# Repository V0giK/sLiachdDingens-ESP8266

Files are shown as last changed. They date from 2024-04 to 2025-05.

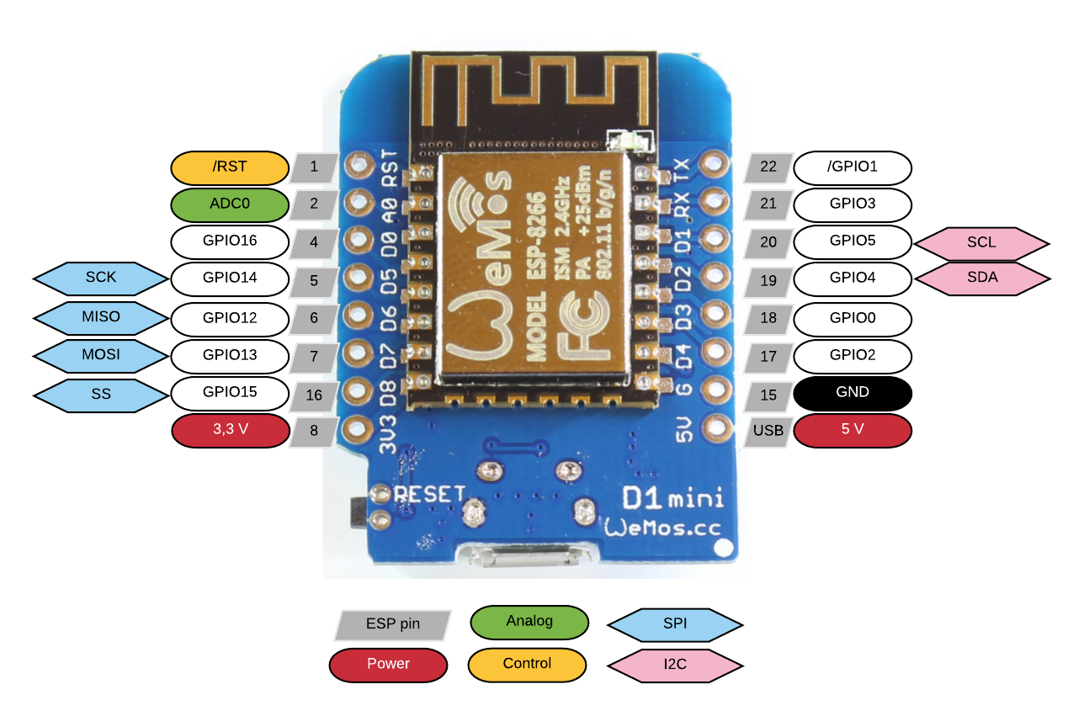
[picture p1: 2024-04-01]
KiCad/WeMos_D1_mini_Pinout.png

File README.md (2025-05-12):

# sLiachdDingens-ESP8266
Einfache 5-Kanal Modellflug Beleuchtungssteuerung

> **under developmet**

- 5 Ports (3x 500mA, 2x 1A)
- je Port 2 Steckplätze
- 1-3 S (Auto Erkennung)
- 3 LightProfile
- Betrieb auch ohne RC Anlage möglich
- Konfiguration über Browser (WLAN-AccessPoint)
	- Akku Überwachung (LowBatt Warnung, CutOff) - Spannungen einstellbar
	- RC Kanal 1 - LightProfile schalten (3 PosSchalter)
	- RC Kanal 2 - LowPower/MaxPower (2 PosSchalter oder Taster)
	- Startposition der RC Kanäle einstellbar (erst nach erreichen dieser Position kann diese geändert werden)
	- Auswählbare Blinksequencen (alle Ausgänge)
	- frei einstellbare Blinksequencen (alle Ausgänge)
	- Firmware Update möglich (OTA)
	- Download der Einstellungen möglich
	- Sicherung des Profils

---

## Aufbau

### Lötreihenfolge
1. SMD Bauteile
2. Kabel
    
### Initial Firmware Upload
> 1. Filesystem Upload - **inkl. HW.json** - (Initialwerte für EEPROM)
> 2. Firmware Upload
> 3. fertig😉

### Komponenten
- ESP8266
- ULA2003A
- ...

---

## Lizenz

Dieses Projekt steht unter der [GNU GPL v3](LICENSE).  
Copyright © 2025 V0giK

Alle Abwandlungen und Forks dieses Projekts müssen ebenfalls
unter den Bedingungen der GNU GPL v3 stehen.

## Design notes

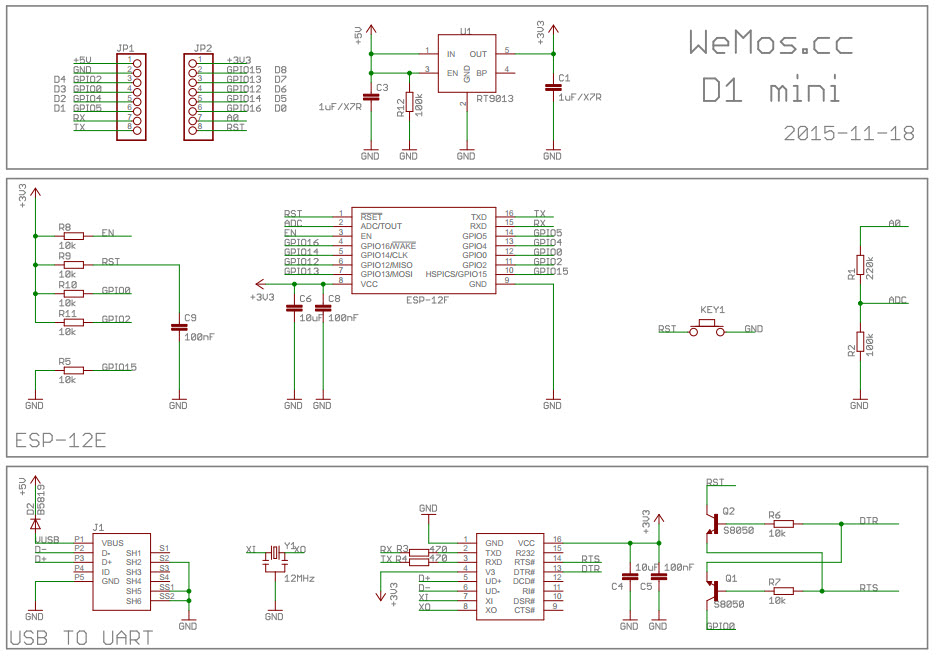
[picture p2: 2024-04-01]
KiCad/WeMos_D1_mini.png

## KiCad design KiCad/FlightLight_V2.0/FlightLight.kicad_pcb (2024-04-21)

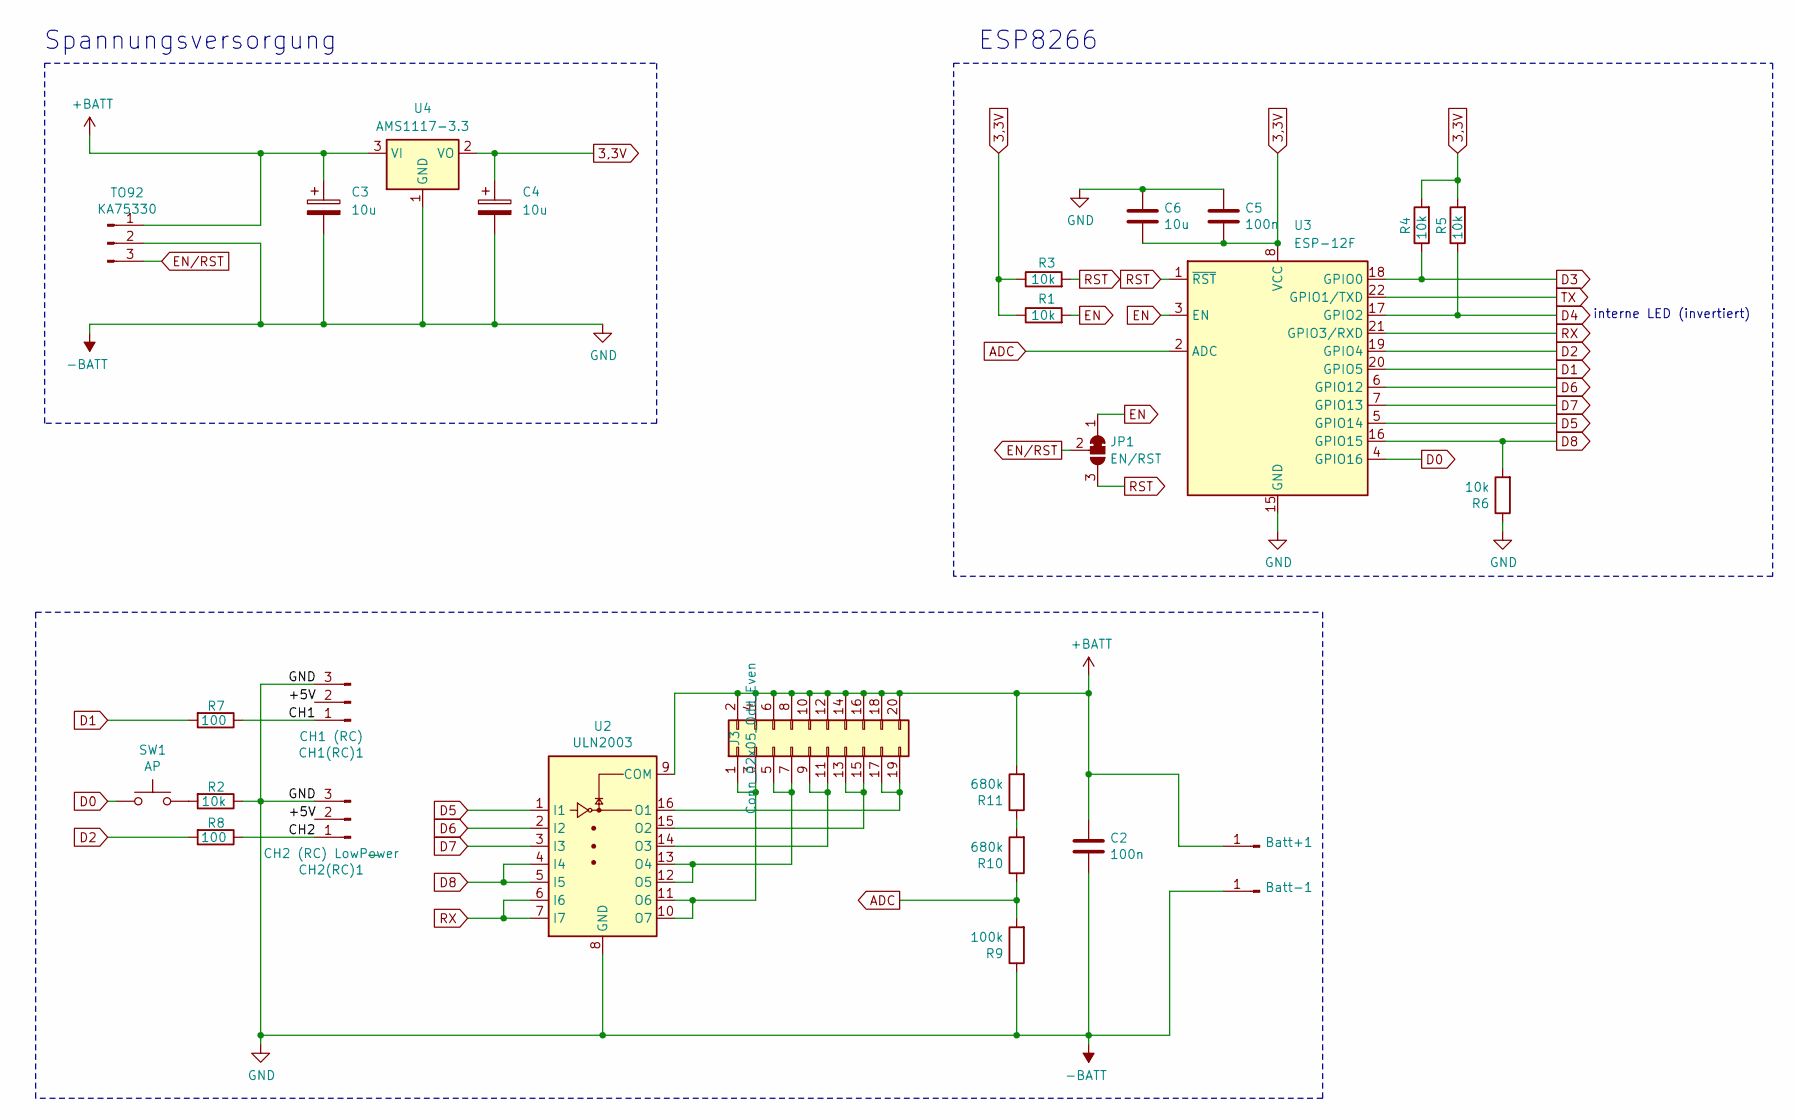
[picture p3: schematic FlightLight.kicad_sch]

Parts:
Batt+1: Batt+; Conn_01x01_2.54
Batt-1: Batt-; Conn_01x01_2.54
C2, C5: 100n; C_0805_2012Metric_Pad1.18x1.45mm_HandSolder
C3, C4, C6: 10u; C_0805_2012Metric_Pad1.18x1.45mm_HandSolder
CH1(RC)1: CH1 (RC); Conn_01x03_2.54_small
CH2(RC)1: CH2 (RC) LowPower; Conn_01x03_2.54_small
J3: Conn_02x05_Odd_Even; PinHeader_2x10_P2.54mm_Vertical
JP1: EN/RST; SolderJumper-3_P1.3mm_Bridged12_RoundedPad1.0x1.5mm
R1, R2, R3, R4, R5, R6: 10k; R_0805_2012Metric_Pad1.20x1.40mm_HandSolder
R7, R8: 100; R_0805_2012Metric_Pad1.20x1.40mm_HandSolder
R9: 100k; R_0805_2012Metric_Pad1.20x1.40mm_HandSolder
R10, R11: 680k; R_0805_2012Metric_Pad1.20x1.40mm_HandSolder
SW1: AP; SW_Push_1P1T_NO_4.5x4.5mm_H7mm
TO92: KA75330; Conn_01x03_2.54_small
U2: ULN2003; SO-16_3.9x9.9mm_P1.27mm
U3: ESP-12F; ESP-12S
U4: AMS1117-3.3; SOT-223-3_TabPin2

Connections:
3,3V: C4.1, C5.2, C6.2, R1.1, R3.1, R4.2, R5.2, U3.8 (VCC), U4.2 (VO)
+BATT: Batt+1.1, C2.1, C3.1, J3.2, J3.4, J3.6, J3.8, J3.10, J3.12, J3.14, J3.16, J3.18, J3.20, R11.2, TO92.1, U2.9 (COM), U4.3 (VI)
-BATT: Batt-1.1, C2.2, C3.2, C4.2, C5.1, C6.1, CH1(RC)1.3, CH2(RC)1.3, R2.1, R6.1, R9.1, TO92.2, U2.8 (GND), U3.15 (GND), U4.1 (GND)
/CH1: CH1(RC)1.1, R7.1
/CH2: CH2(RC)1.1, R8.1
ADC: R9.2, R10.1, U3.2 (ADC)
D0: SW1.1, U3.4 (GPIO16)
D1: R7.2, U3.20 (GPIO5)
D2: R8.2, U3.19 (GPIO4)
D3: R4.1, U3.18 (GPIO0)
D4: R5.1, U3.17 (GPIO2)
D5: U2.1 (I1), U3.5 (GPIO14)
D6: U2.2 (I2), U3.6 (GPIO12)
D7: U2.3 (I3), U3.7 (GPIO13)
D8: R6.2, U2.4 (I4), U2.5 (I5), U3.16 (GPIO15)
EN: JP1.1 (A), R1.2, U3.3 (EN)
EN/RST: JP1.2 (C), TO92.3
unnamed: J3.1, J3.3, U2.10 (O7), U2.11 (O6)
unnamed: J3.5, J3.7, U2.12 (O5), U2.13 (O4)
unnamed: J3.9, J3.11, U2.14 (O3)
unnamed: J3.13, J3.15, U2.15 (O2)
unnamed: J3.17, J3.19, U2.16 (O1)
unnamed: R2.2, SW1.2
unnamed: R10.2, R11.1
RST: JP1.3 (B), R3.2, U3.1 (~RST)
RX: U2.6 (I6), U2.7 (I7), U3.21 (GPIO3/RXD)
TX: U3.22 (GPIO1/TXD)

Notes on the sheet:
ESP8266
Spannungsversorgung
interne LED (invertiert)

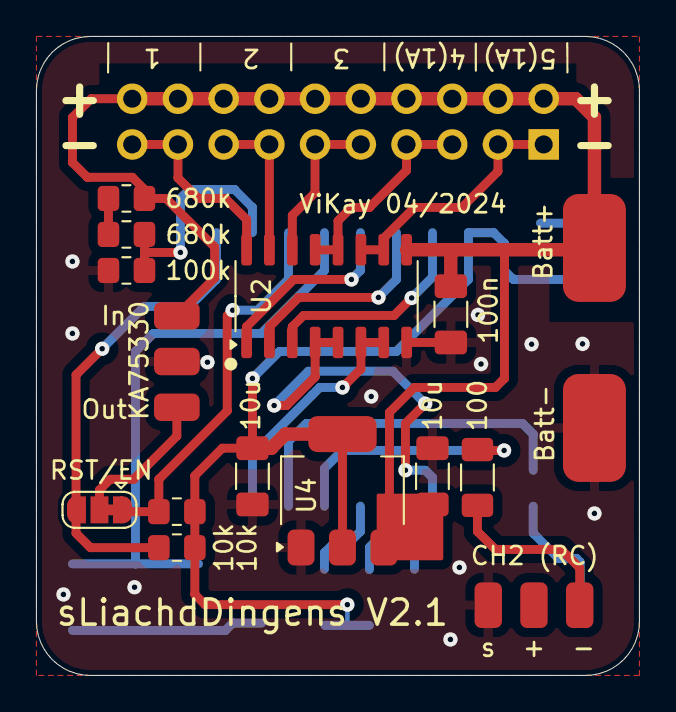
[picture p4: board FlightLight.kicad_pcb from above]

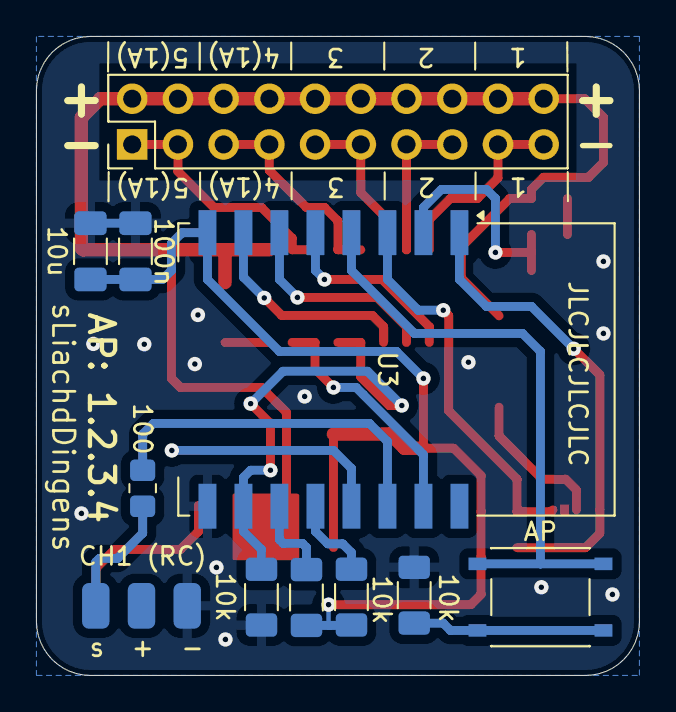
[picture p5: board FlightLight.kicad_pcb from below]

Board: 2 copper layers, 33.5 x 35.5 mm, 27 parts (11 on the bottom side), 26 nets.

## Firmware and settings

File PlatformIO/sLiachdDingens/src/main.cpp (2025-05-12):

// maim.cpp
/*
  Projekt: sLiachdDingens-ESP8266
  Copyright © 2025 V0giK

  Dieses Programm ist freie Software: Du kannst es unter den Bedingungen
  der GNU General Public License, wie von der Free Software Foundation
  veröffentlicht, weitergeben und/oder modifizieren – entweder gemäß
  Version 3 der Lizenz oder (nach Deiner Wahl) einer späteren Version.

  Der vollständige Lizenztext ist in der Datei LICENSE enthalten:
  https://github.com/V0giK/sLiachdDingens-ESP8266/blob/main/LICENSE
*/


#include <LittleFS.h>
//#include <Wire.h>

#include "main.h"
#include "Settings.h"
#include "GlobalFnc.h"
#include "RcSwitchHelper.h"


#include "globalvariables.h"
//#include "I2C_Anything.h"
#include "WiFi_WebServerHandling.h"


/* Input Pins */
#define PIN_AP D0   // AP aktivieren
#define PIN_CH_PR D1   // CH1 Profile schalten (Servoeingang)
#define PIN_CH_LP D2   // CH2 für LowPower mode
#define PIN_BATT A0 // Spannungsüberwachung Batt
/* Output Pins */
#define PIN_APACT D4  // AP aktiv (LED)
#define PIN_O1 D5
#define PIN_O2 D6
#define PIN_O3 D7
#define PIN_O4 D8
#define PIN_O5 3 // ist RX
const uint8_t outPinAr[] = {PIN_O1, PIN_O2, PIN_O3, PIN_O4, PIN_O5};

//bool bStartPrev = false;  // Loop anhalten bis alle Variablen neu bestückt sind (INI neu laden)

/* Slot Zeit */
unsigned long prevMillis = 0;   // speichert die letzte zeit des Slots
const long interval = 60;       // Interval bis nächster Slot beginnt (milliseconds)

/* RC Signal auswerten */
volatile ITR_STRUCT ITR_Ch1;
volatile ITR_STRUCT ITR_Ch2;

/* RC Schalter */
RcSwitchHelper gCH1;
RcSwitchHelper gCH2;

bool _bPrev = false; // Loop anhalten bis alle Variablen neu bestückt sind (.json neu laden)
WiFi_WebServerHandling webServer;

/***********************************************************************************************************/


void setup() {

  #ifdef DEV_SERIAL_OUT
  Serial.begin(SERIAL_SPEED);
  #endif
  if(!LittleFS.begin()) {
    #ifdef DEV_SERIAL_OUT
    Serial.println("LittleFS Mount nicht gelungen");
    #endif
  }

    /* EEPROM lesen */
  //gEeprom.loadEeprom(); // aus EEPROM
  // EEPROM beschreiben falls neue HardwareDaten vorhanden sind (HW.json)
  if(LittleFS.exists(PATH_HW)) {
    gJsonHelper.readDeleteEraseJsonHW(gEeprom);
    gEeprom.saveEeprom();

    // TODO : oder weiter machen?
    delay(200);
    ESP.restart();
  } else {
    gEeprom.loadEeprom(); // aus EEPROM
  }

  // JsonHelper initialisieren
  gJsonHelper.begin(gEeprom.getPortCount(), gEeprom.getProfileCount(), gEeprom.getSlotCount());
  
  // Config laden
  gJsonHelper.loadJsonConfig();
  // Sequence laden
  gJsonHelper.loadJsonSequence();

  // BattHelper initialisieren
  gBatt.begin(PIN_BATT, gJsonHelper.getConfigBattWarningVolt(), gJsonHelper.getConfigBattCutOffVolt(), gEeprom.getBattCalibFactor(), BATT_WARN_LOW);

  // RC Schalter initialisieren
  gCH1.begin((gJsonHelper.getSequence()->ch1Boot == 2)?1:gJsonHelper.getSequence()->ch1Boot, (gJsonHelper.getSequence()->ch1Boot == 2));
  gCH2.begin((gJsonHelper.getSequence()->ch2Boot == 2)?1:gJsonHelper.getSequence()->ch2Boot, (gJsonHelper.getSequence()->ch2Boot == 2));
  ITR_Ch1.bIsToggleSwitsch = gCH1.isToggleSwitch();
  ITR_Ch2.bIsToggleSwitsch = gCH2.isToggleSwitch();
  
  
  /* WiFi deaktivieren */
  // Wird im Constructor erledigt
  //webServer.disableWifi();

  // Serial Pin's auf GPIO tauschen  
  //pinMode(1, FUNCTION_3);  //GPIO 1 (TX) swap the pin to a GPIO.
  pinMode(3, FUNCTION_3);  //GPIO 3 (RX) swap the pin to a GPIO.

  // PinMode
  pinMode(PIN_AP, INPUT_PULLUP); // kein interner PULLUP vorhanden nur PULLDOWN
  pinMode(PIN_CH_PR, INPUT);
  pinMode(PIN_CH_LP, INPUT);
  pinMode(PIN_BATT, INPUT);
  pinMode(PIN_APACT, OUTPUT);
  pinMode(PIN_O1, OUTPUT);
  pinMode(PIN_O2, OUTPUT);
  pinMode(PIN_O3, OUTPUT);
  pinMode(PIN_O4, OUTPUT);
  pinMode(PIN_O5, OUTPUT);
  //attachInterrupt(PIN_SV, RcChange, CHANGE);
  attachInterrupt(digitalPinToInterrupt(PIN_CH_PR), RcCalcChange, CHANGE);
  attachInterrupt(digitalPinToInterrupt(PIN_CH_LP), RcLowPwrChange, CHANGE);
  
    // I2C Starten
  #ifndef DEV_SERIAL_OUT

  /*
    pinMode(1, FUNCTION_3);  //GPIO 1 (TX) swap the pin to a GPIO.
    pinMode(3, FUNCTION_3);  //GPIO 3 (RX) swap the pin to a GPIO.
    delay(200);
    Wire.begin(1, 3);
  */

    /*
     * I2C Scannen
     * - prüfen ob für Adresse ein .json vorhanden ist
     * - wenn ja Adresse in Array aufnehmen
     */
    /*
    byte i = 0;
    for(byte adr=8; adr<120; adr++){
      if(i >= EXPAND_MAX)
        break;
      Wire.beginTransmission(adr);
      if(0 == Wire.endTransmission()){
        // noch prüfen ob Exp??.json vorhanden
        if(LittleFS.exists(PATH_JSON + String("/Exp") + String(adr) + ".json")){
          gExpandAdresses[i] = adr;
          i++;
        }
      }
    }
    */
  #endif

  // Vorbelegung für den Start
  gLowPwr = gJsonHelper.getSequence()->lowPwrPercent;
  

  /*
  Wire.beginTransmission(0);
  Wire.write("W1");
  Wire.write(gPosCH1);
  Wire.write("W2");
  Wire.write(gPosCH2);
  Wire.endTransmission();
  */
  

  // Access Point aktivieren wenn Taster gedrückt
  digitalWrite(PIN_APACT, HIGH);     // AP LED off

  if(!digitalRead(PIN_AP) || DBG_AP_ON) {
    webServer.AP_starten();
    digitalWrite(PIN_APACT, LOW);  // AP LED on
  }else{
    //WiFi.mode(WIFI_SHUTDOWN);
  }

  // warten bis RC Anlage gebunden sein müsste
  delay(500);

}

void loop() {

  /* Position CH1 */
  /* Position CH2 */
  handleRcChannels();



  unsigned long curMillis = millis();
  if (curMillis - prevMillis >= interval && !getPrev()) {
    prevMillis = curMillis;

    /* VBatt */
    if(giCurSlot % 4 == 1) { // 20 Slots % 4 = 0-3; nach jeweils 4 Slots erneut prüfen (4x 0,06sec = 0,24sec)

      // Batterie Daten aktualisieren
      gBatt.refresh();
      
      // Unterspannung
      // CutOff
      if(gBatt.isCutOff()){
        setAllLightPortsOff();
        mapSlot2Port(0);
        delay(200);
        ESP.deepSleep(ESP.deepSleepMax());
      }
    }
    /* end - VBatt */

    if(giCurSlot >= gEeprom.getSlotCount()) giCurSlot = 0;
    
    // Ausgabe an die Ports
    mapSlot2Port(giCurSlot);

    #ifndef DEV_SERIAL_OUT
    /*
    Wire.beginTransmission(0);
    Wire.write("S"); Wire.write(giCurSlot);
    Wire.endTransmission();
    */
    #endif

    giCurSlot++;
    yield();
  }
  //ESP.wdtDisable(); 

}

/**
 * Slots an die Pins ausgeben
 */
void mapSlot2Port(uint8_t slot){
  for(byte i=0; i<sizeof(outPinAr); i++){
    analogWrite(outPinAr[i], seqSlotVal(i, gCH1.getPosition(), slot)*(gLowPwr/100.0)*(gJsonHelper.getSequence()->pwr[GlobalFnc::MA(i, gCH1.getPosition())]/100.0)*(gBatt.getWarnPwr()/100.0));
  }
}

/**
 * Slot Value auf Ausgabewert umrechnen
*/
long seqSlotVal(uint8_t port, uint8_t profile, uint8_t slot){
  return map(gJsonHelper.getSequence()->seq[GlobalFnc::MA(port, profile, slot)], 0, 8, 0, 1023);
}

/**
 * Alle LightPorts auf Parameter setzen
 * 
 * Parameter:
 * val - gewünschter Wert (0-1023)
 */
void setAllLightPorts(uint8_t val){
  for(uint8_t x = 0; x < gEeprom.getPortCount(); x++) {
    for(uint8_t prof=0; prof < gEeprom.getProfileCount(); prof++) {
      for(uint8_t y = 0; y < gEeprom.getSlotCount(); y++) {
          gJsonHelper.getSequence()->seq[GlobalFnc::MA(x, prof, y)] = val;
      }
    }
  }
}
void setAllLightPortsOff() {
  setAllLightPorts(0);
}


void handleRcChannels() {
  /* Position CH1 */
  if(ITR_Ch1.bHasBooking){
    gCH1.setPosition(ITR_Ch1.newVal);
    ITR_Ch1.bHasBooking = false;
  }

  /* Position CH2 */
  // LowPower Mode
  if(ITR_Ch2.bHasBooking) {
    gCH2.setPosition(ITR_Ch2.newVal);
    // LowPower festlegen
    if(gCH2.getPosition() == 0){
      gLowPwr = gJsonHelper.getSequence()->lowPwrPercent;
    } else {
      gLowPwr = 100;
    }
    ITR_Ch2.bHasBooking = false;
  }
}

/**
 * Daten für Vorschau vorbereiten und dadurch in loop() nichts ausführen
 */
void setPrev(bool val){
    _bPrev = val;
}
bool getPrev() {
    return _bPrev;
}



//--------ISR--------
void RcCalcChange(){
  noInterrupts();
  
  if(digitalRead(PIN_CH_PR) == HIGH) {
    ITR_Ch1.startTime = micros();
  } else if(ITR_Ch1.startTime && !ITR_Ch1.bHasBooking) {

    ITR_Ch1.pulseLength = (volatile int)(micros() - ITR_Ch1.startTime);

    // 1000 - 2000 (1500 ist Mittelstellung)
    if(ITR_Ch1.pulseLength > 900) {
      if(ITR_Ch1.pulseLength <= 1333) {
        ITR_Ch1.newVal = 0;
      } else if(ITR_Ch1.pulseLength <= 1666) {
        ITR_Ch1.newVal = 1;
      } else {
        ITR_Ch1.newVal = 2;
      }
      ITR_Ch1.bHasBooking = true;
    }

    ITR_Ch1.startTime = 0;
  }
  
  interrupts();
}

void RcLowPwrChange(){
  static uint8_t tasterNormal = 0, tasterNow = 0;
  static bool tgFirst = true;
  
  noInterrupts();
  if(digitalRead(PIN_CH_LP) == HIGH) {
    ITR_Ch2.startTime = micros();
  } else if(ITR_Ch2.startTime && !ITR_Ch2.bHasBooking) {
    ITR_Ch2.pulseLength = (volatile int)(micros() - ITR_Ch2.startTime);

    // Position
    if(ITR_Ch2.pulseLength > 900) {
      if( ITR_Ch2.pulseLength < 1550 )
        ITR_Ch2.newVal = 0;
      else
        ITR_Ch2.newVal = 1;
    }

    if(ITR_Ch2.bIsToggleSwitsch){
        if(tgFirst){
            tgFirst = false;
            tasterNormal = ITR_Ch2.newVal;
            tasterNow = ITR_Ch2.newVal;
        } else {
            // Toggle
            //if(_tasterNow != _tasterNormal && _tasterNow != gNewPosCH2){ // Toggle on release button
            if(tasterNow == tasterNormal && tasterNow != ITR_Ch2.newVal){ // Toggle on press button
                ITR_Ch2.bHasBooking = true;
            }
            tasterNow = ITR_Ch2.newVal;
        }

    } else {
        ITR_Ch2.bHasBooking = true;
    }


    ITR_Ch2.startTime = 0;
  }
  interrupts();
}

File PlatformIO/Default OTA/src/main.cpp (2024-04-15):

/*
  -----------------------
  ElegantOTA - Async Demo Example
  -----------------------

  NOTE: Make sure you have enabled Async Mode in ElegantOTA before compiling this example!
  Guide: https://docs.elegantota.pro/async-mode/

  Skill Level: Beginner

  This example provides with a bare minimal app with ElegantOTA functionality which works
  with AsyncWebServer.

  Github: https://github.com/ayushsharma82/ElegantOTA
  WiKi: https://docs.elegantota.pro

  Works with both ESP8266 & ESP32

  -------------------------------

  Upgrade to ElegantOTA Pro: https://elegantota.pro

*/

#if defined(ESP8266)
  #include <ESP8266WiFi.h>
  #include <ESPAsyncTCP.h>
  #include <ESP8266mDNS.h>
#elif defined(ESP32)
  #include <WiFi.h>
  #include <AsyncTCP.h>
#endif

#include <ESPAsyncWebServer.h>
#include <AsyncElegantOTA.h>

const char* ssid = "TP-Link_991A";
const char* password = "71420530";

AsyncWebServer server(80);

unsigned long ota_progress_millis = 0;

void onOTAStart() {
  // Log when OTA has started
  Serial.println("OTA update started!");
  // <Add your own code here>
}

void onOTAProgress(size_t current, size_t final) {
  // Log every 1 second
  if (millis() - ota_progress_millis > 1000) {
    ota_progress_millis = millis();
    Serial.printf("OTA Progress Current: %u bytes, Final: %u bytes\n", current, final);
  }
}

void onOTAEnd(bool success) {
  // Log when OTA has finished
  if (success) {
    Serial.println("OTA update finished successfully!");
  } else {
    Serial.println("There was an error during OTA update!");
  }
  // <Add your own code here>
}

void setup(void) {
  Serial.begin(115200);
  WiFi.mode(WIFI_STA);
  WiFi.hostname("initialOTA");
  WiFi.begin(ssid, password);
  Serial.println("");

  MDNS.begin("initialOTA");

  // Wait for connection
  while (WiFi.status() != WL_CONNECTED) {
    delay(500);
    Serial.print(".");
  }
  Serial.println("");
  Serial.print("Connected to ");
  Serial.println(ssid);
  Serial.print("IP address: ");
  Serial.println(WiFi.localIP());

  server.on("/", HTTP_GET, [](AsyncWebServerRequest *request) {
    request->send(200, "text/plain", "Hi! This is ElegantOTA AsyncDemo.");
  });


  AsyncElegantOTA.begin(&server);    // Start ElegantOTA


  server.begin();
  Serial.println("HTTP server started");

  pinMode(D4, OUTPUT);
  digitalWrite(D4,LOW);
}

void loop(void) {
  MDNS.update();
  AsyncElegantOTA.loop();
}

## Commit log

2024-04-01 Add files via upload
    Initial upload
    [FlightLight.kicad_pcb, FlightLight.kicad_sch, FlightLight.sch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]
2024-04-02 panelize ausgerichtet
    [FlightLight-panelized.kicad_pcb, FlightLight.kicad_pcb]
2024-04-03 new panelized
    [FlightLight-panelized.kicad_pcb]
2024-04-15 Board Fix
2024-04-15 Nach WLAN Login LED an.
2024-04-15 Fix V2.1 - Pin TX nicht verwenden
    [FlightLight.kicad_pcb, FlightLight.kicad_sch]
2024-04-15 Fix EEPROM read bei HW.json
    [JsonHelper2.cpp]
2024-04-21 PCB V2.1
    kleine Fixes
    [FlightLight-panelized.kicad_pcb, FlightLight.kicad_pcb, FlightLight.kicad_sch]
